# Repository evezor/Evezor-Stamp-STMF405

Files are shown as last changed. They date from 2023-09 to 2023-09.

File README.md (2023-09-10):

# Evezor-Stamp-STMF405
*please note this board is has been deprecated. 

The Evezor Stamp is a castellated carrier for the stmf405 chip with CAN networking and memory for Evezor's Edge network

The intent was that I could have this made by a higher quality shop with better pick and place machines than I had at the time. 
This was originally designed early in the pandemic and then the STM chips became completely unavailable. 
It worked pretty good, but in the end I'm glad I changed chipsets for a number of reasons. 
For one, I think I would have not liked using these so much. The boards I designed for this had this module on the back. Don't do double sided stuff unless absolutely necessary. Additionally, changing chips right in the early stages provided me with the knowledge of the location of the boundaries between chips. This was and is good knowledge. 

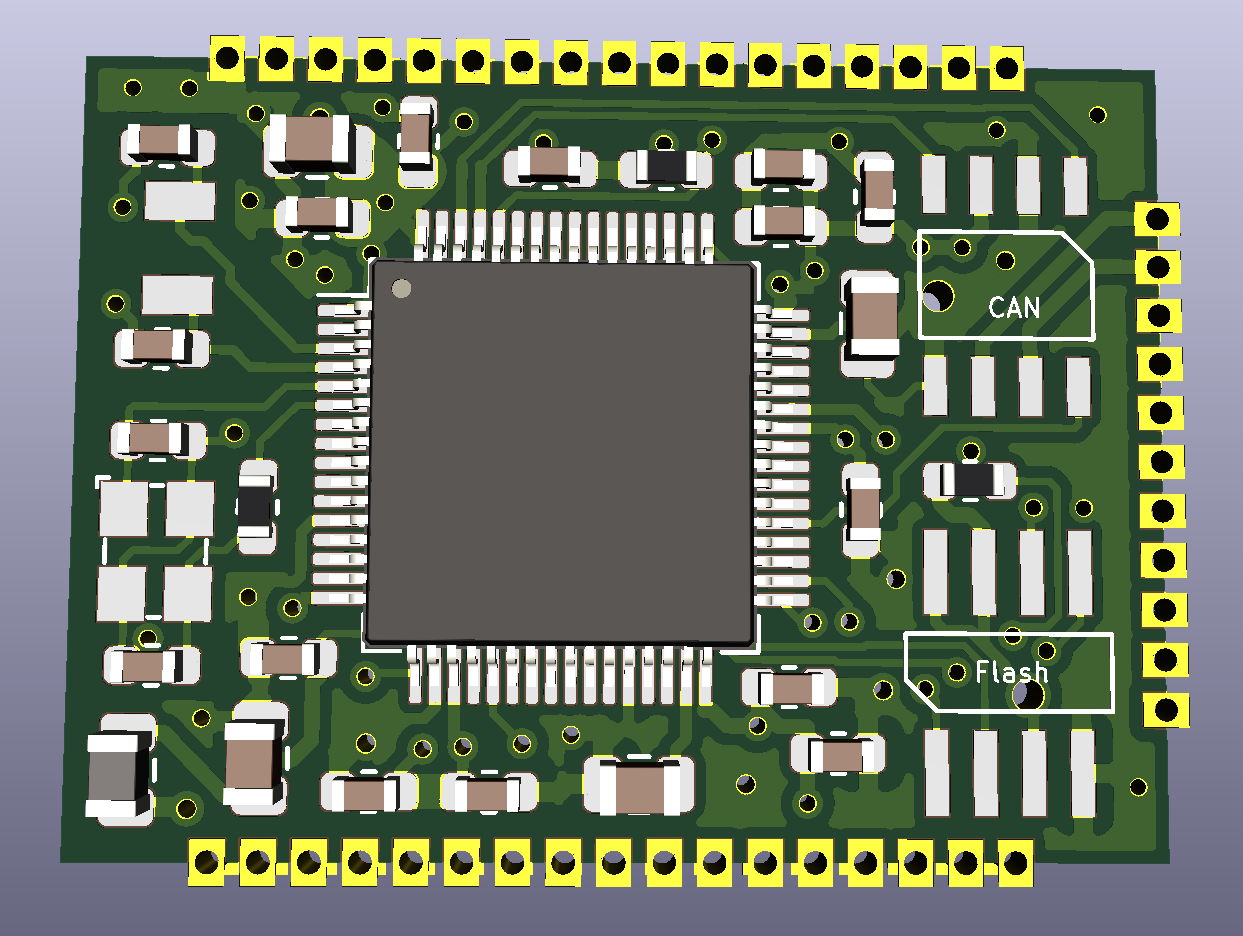
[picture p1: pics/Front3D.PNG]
front_view


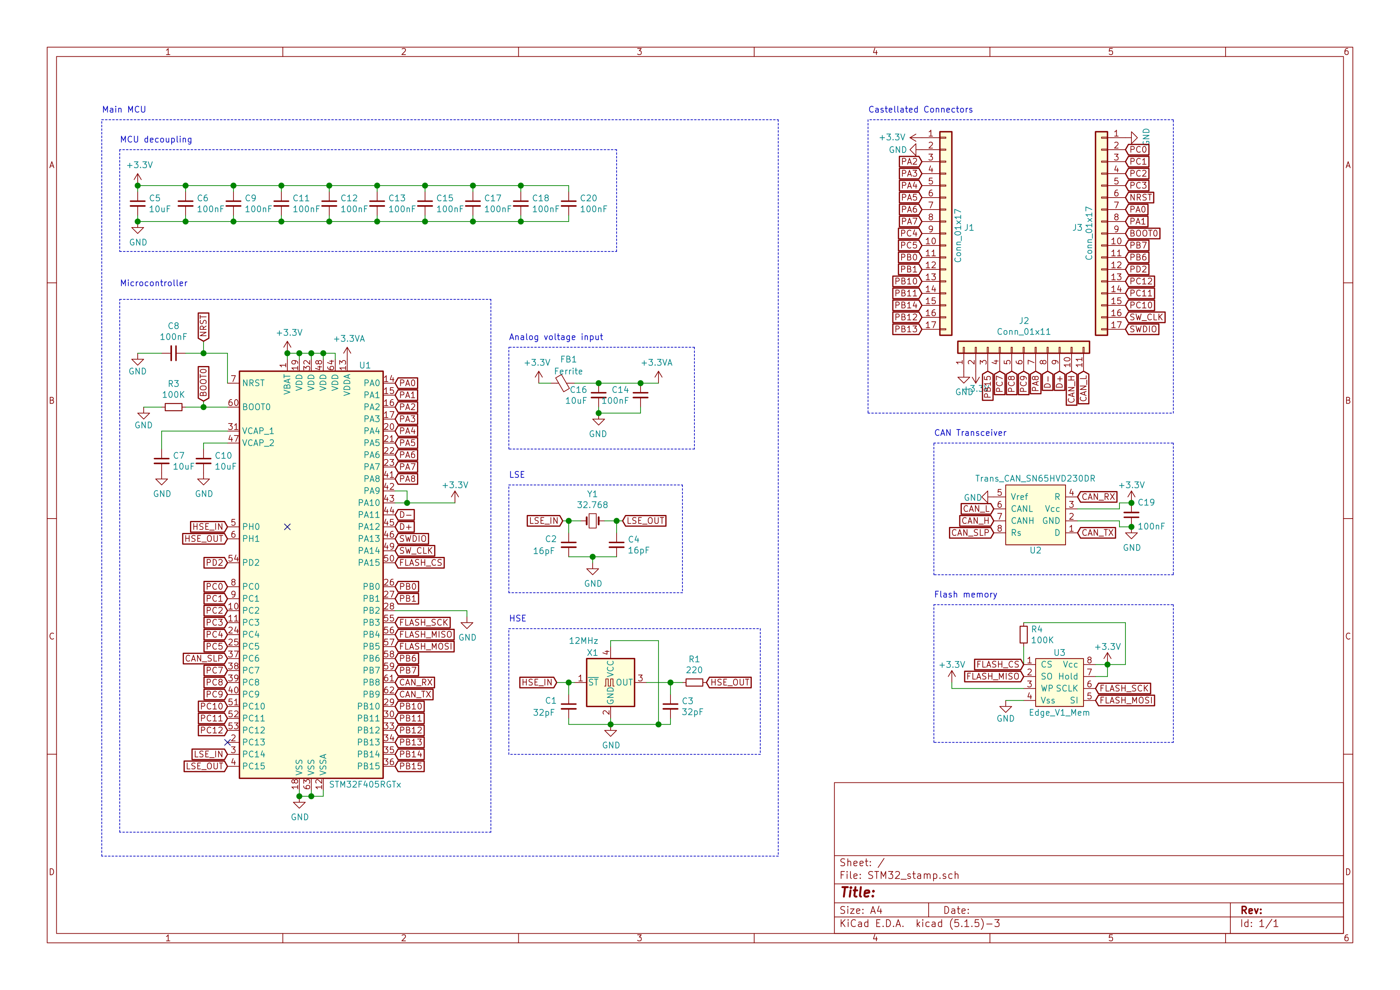
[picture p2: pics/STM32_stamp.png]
schematic


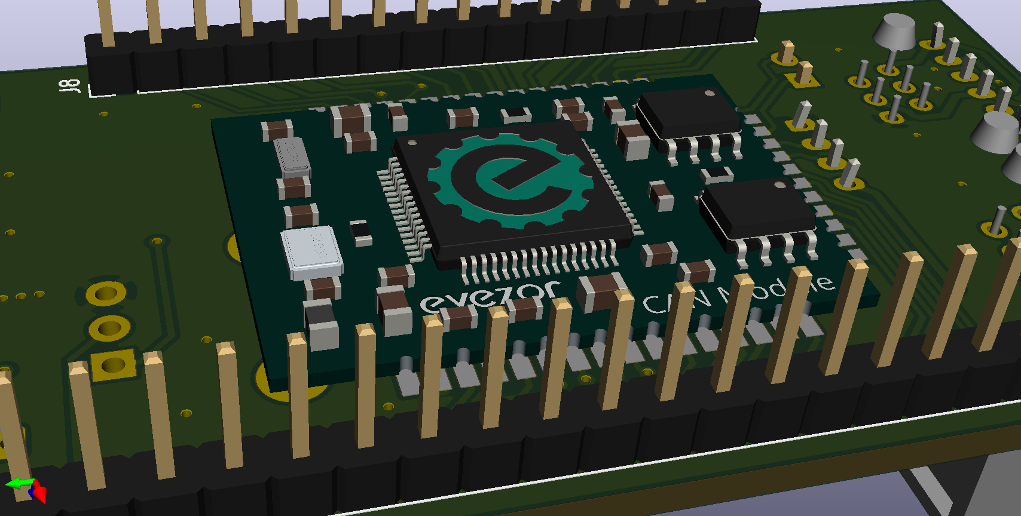
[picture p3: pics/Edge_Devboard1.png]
3d


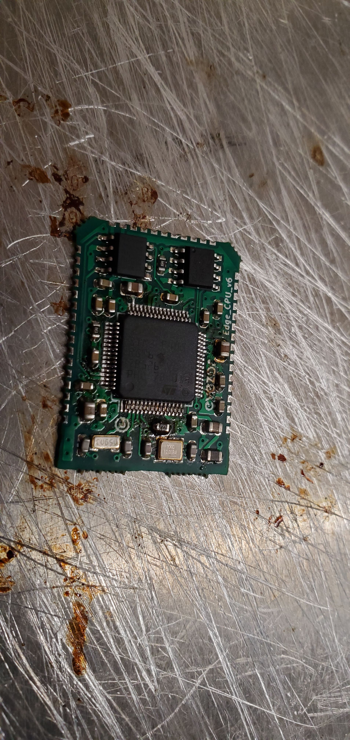
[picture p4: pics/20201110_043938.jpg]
stamp


I also developed a test and programming jig. It worked ok as well.
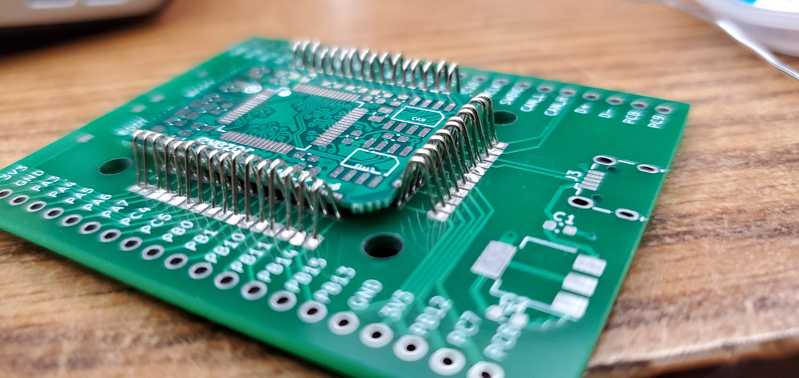
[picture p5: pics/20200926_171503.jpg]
test


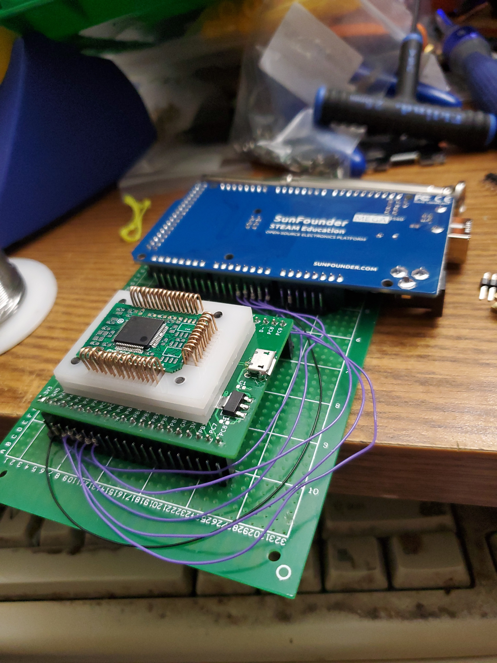
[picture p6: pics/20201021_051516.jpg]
mega


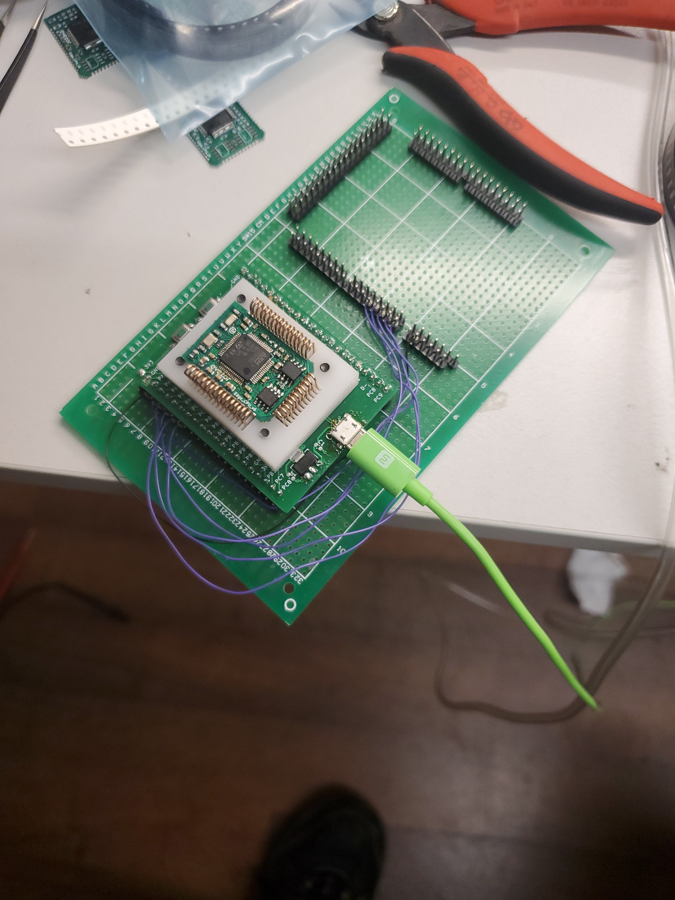
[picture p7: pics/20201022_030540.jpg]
empty


Evezor® and all associated marks, logos, and designs are registered trademarks and protected by copyright. Unauthorized use or reproduction of these trademarks and copyrighted materials is strictly prohibited

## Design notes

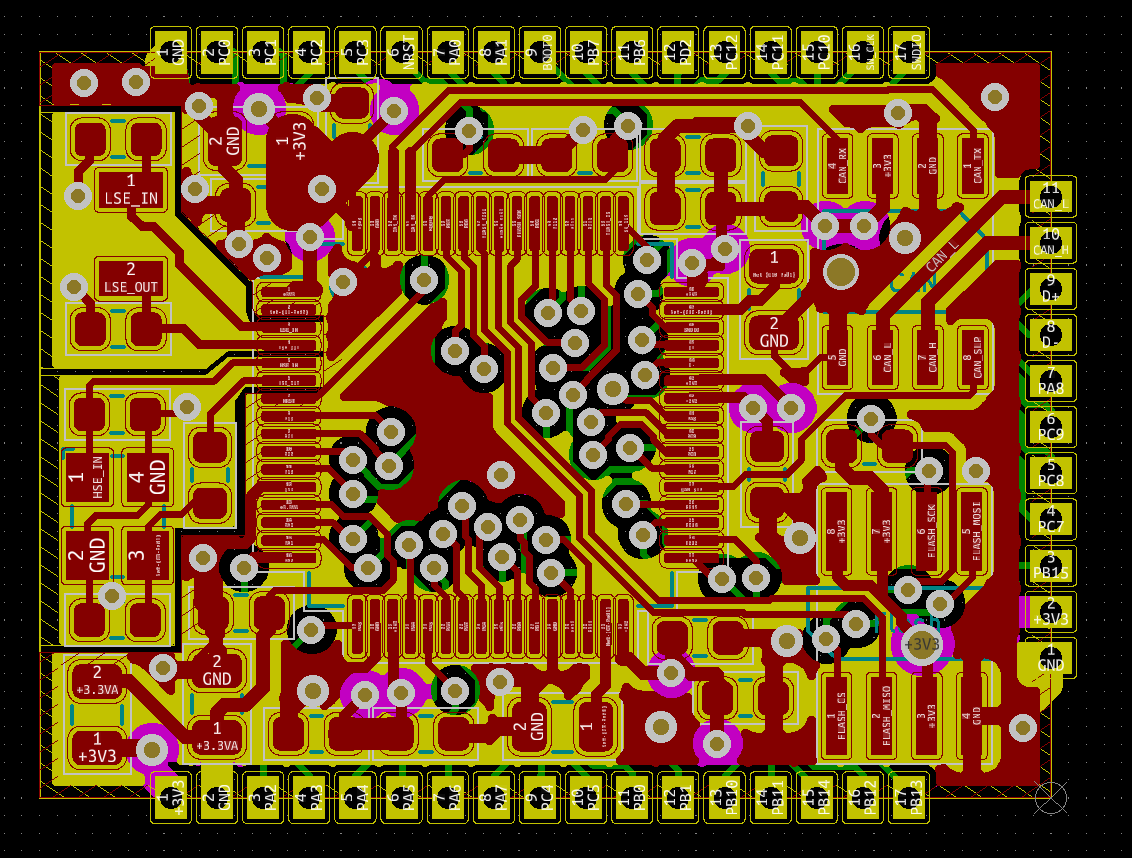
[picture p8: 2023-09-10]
pics/FrontCopper.PNG

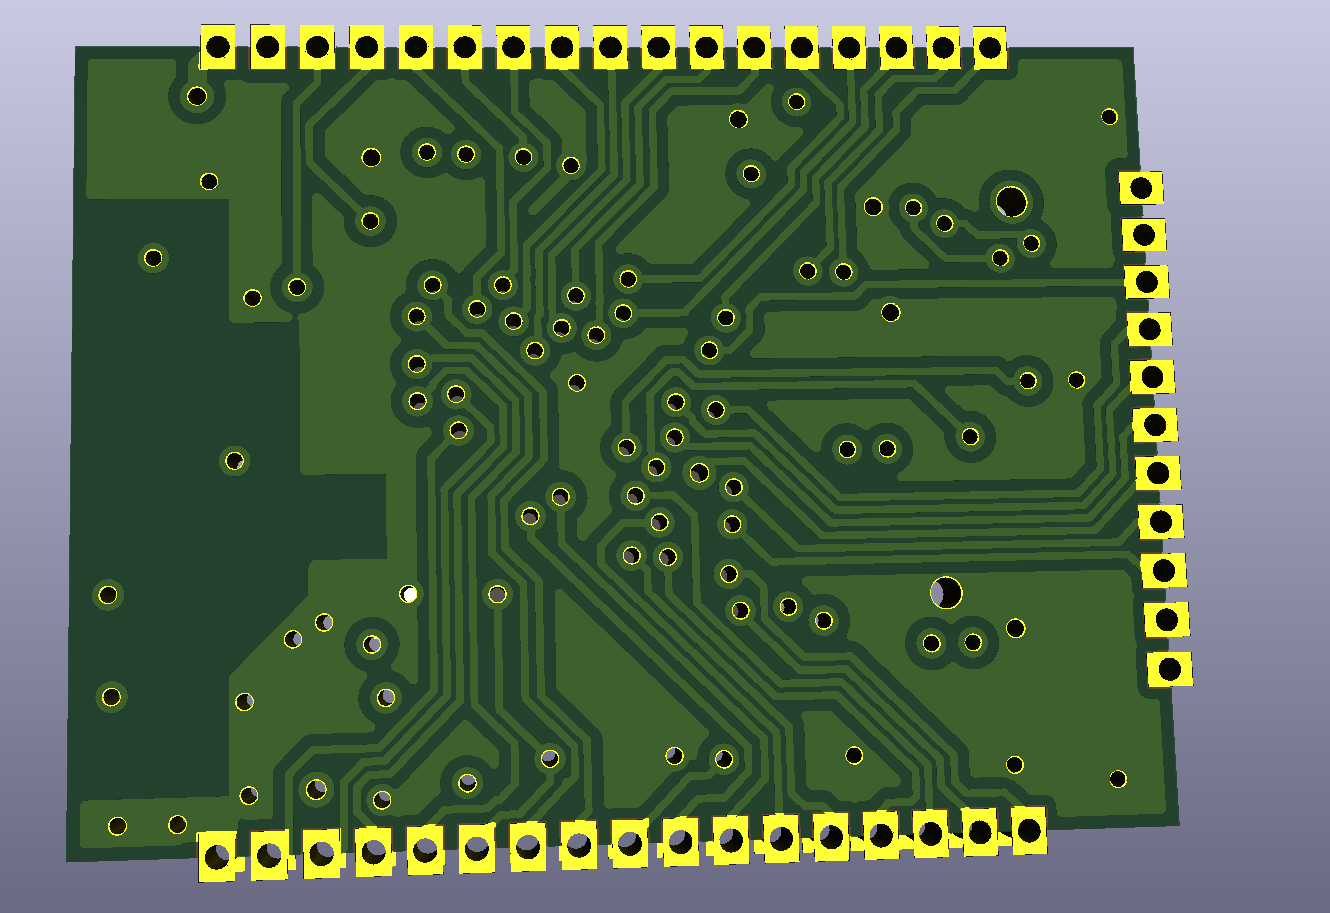
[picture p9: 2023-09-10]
pics/Back3D.PNG

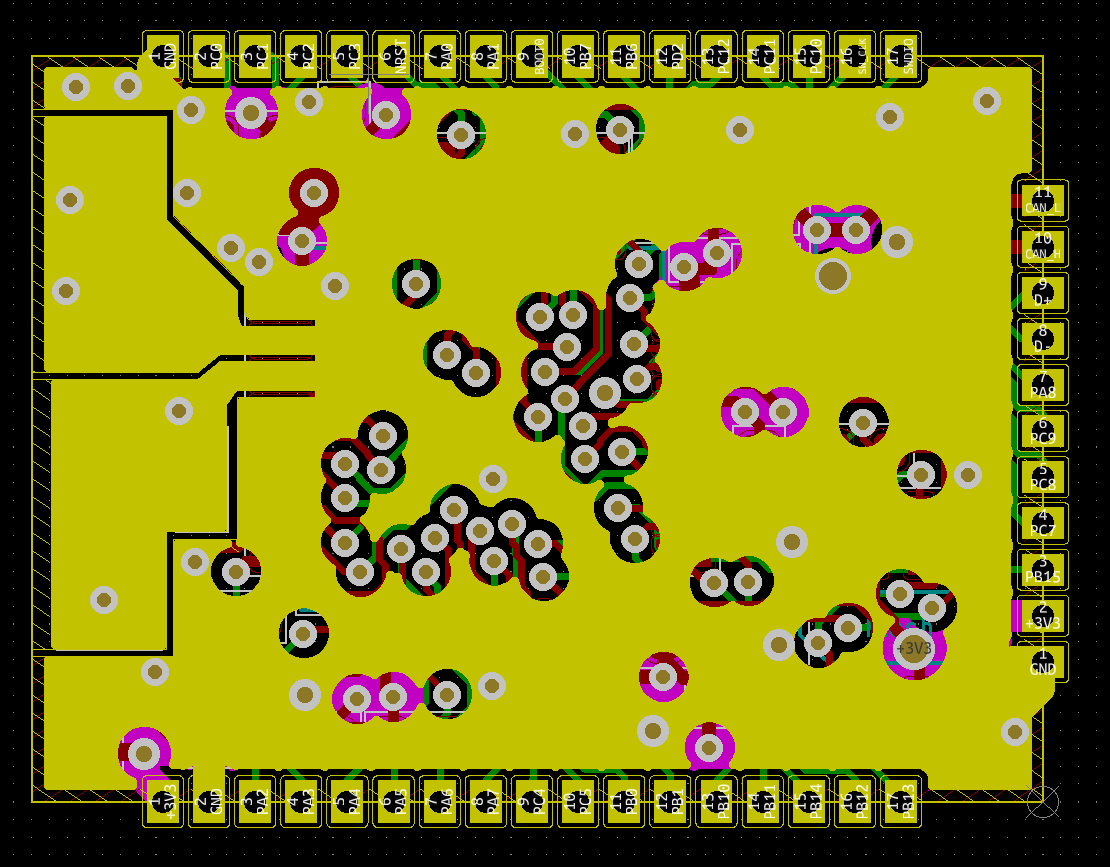
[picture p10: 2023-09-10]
pics/GroundPour.PNG

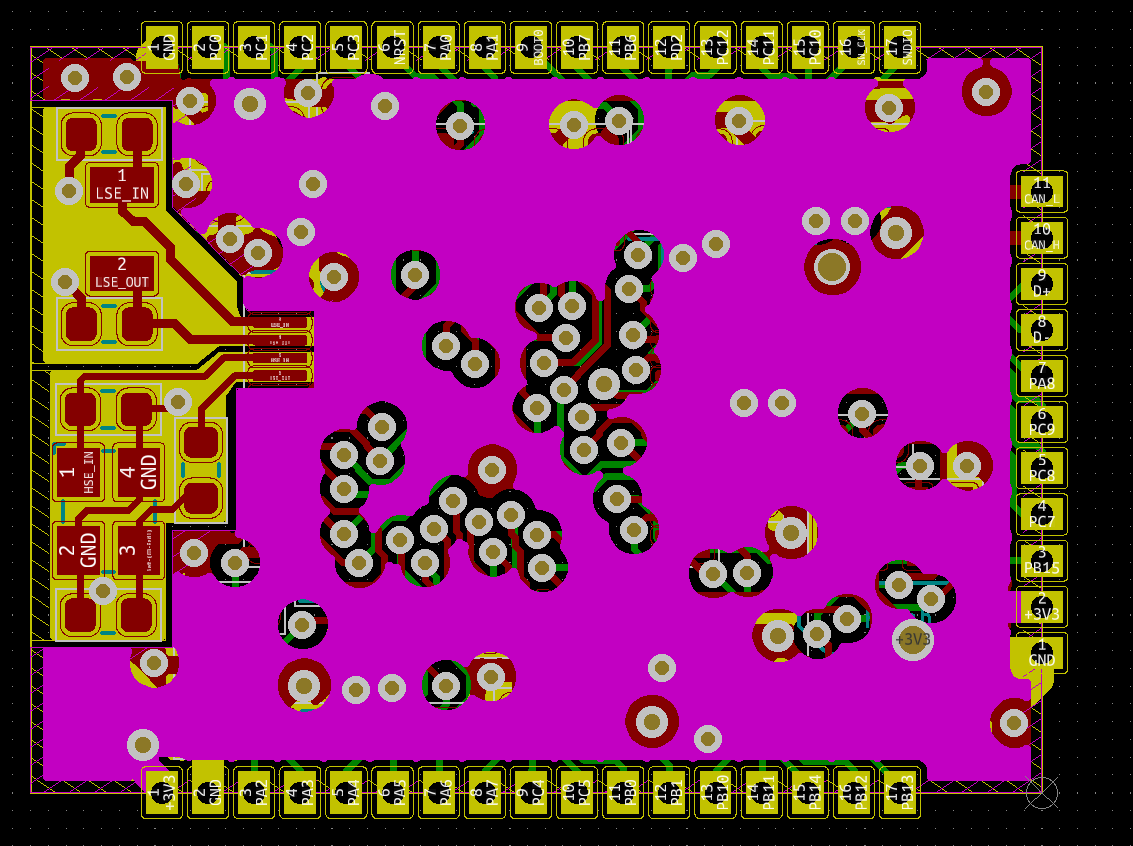
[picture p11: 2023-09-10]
pics/3V3.PNG

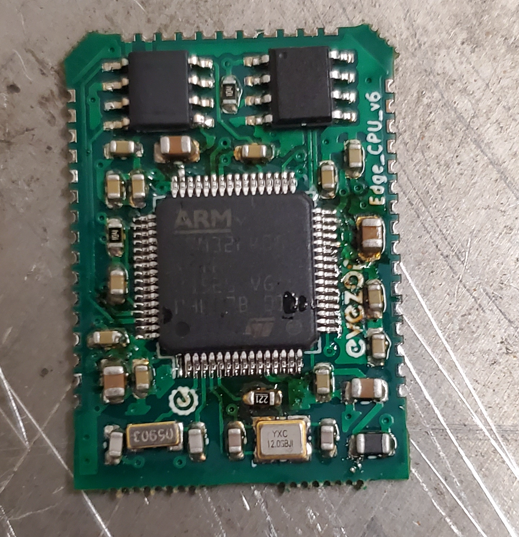
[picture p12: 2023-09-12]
pics/sm.PNG

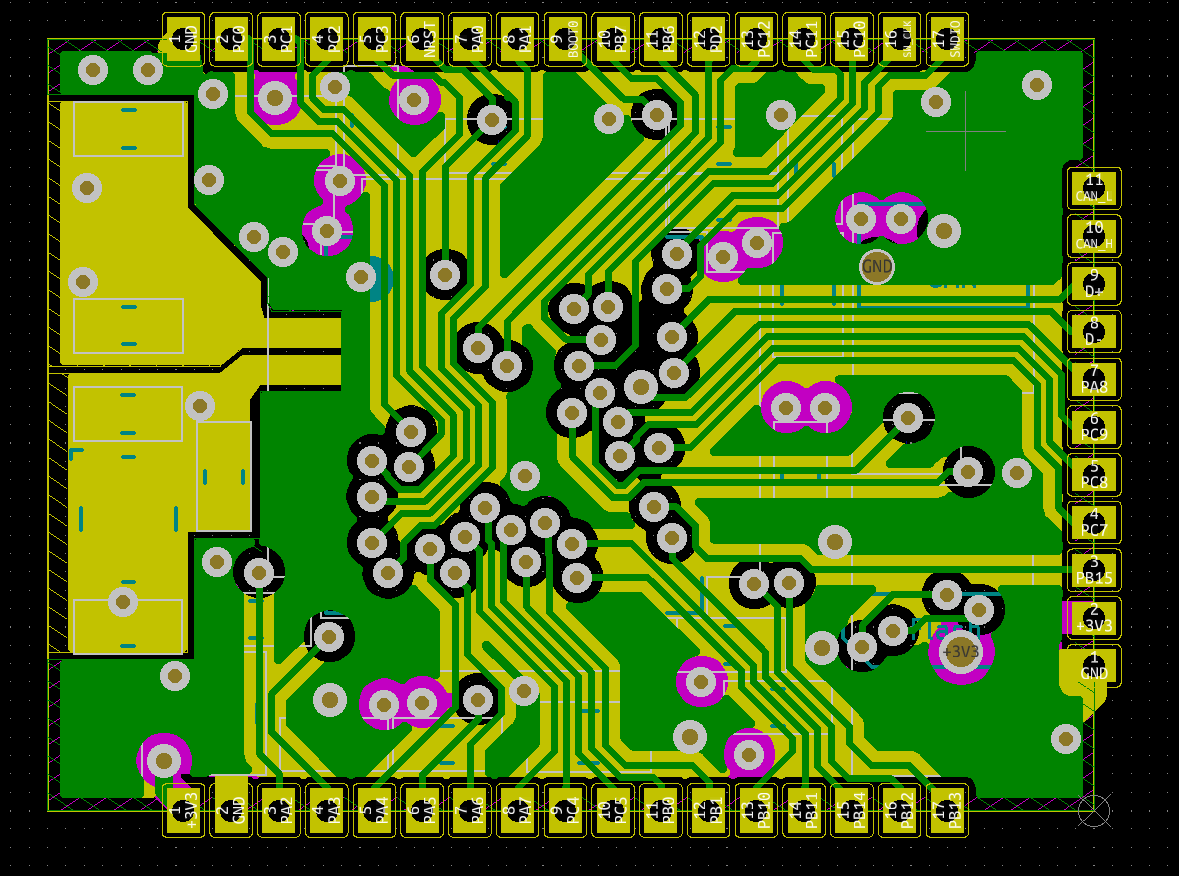
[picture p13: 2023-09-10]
pics/BackCopper.PNG

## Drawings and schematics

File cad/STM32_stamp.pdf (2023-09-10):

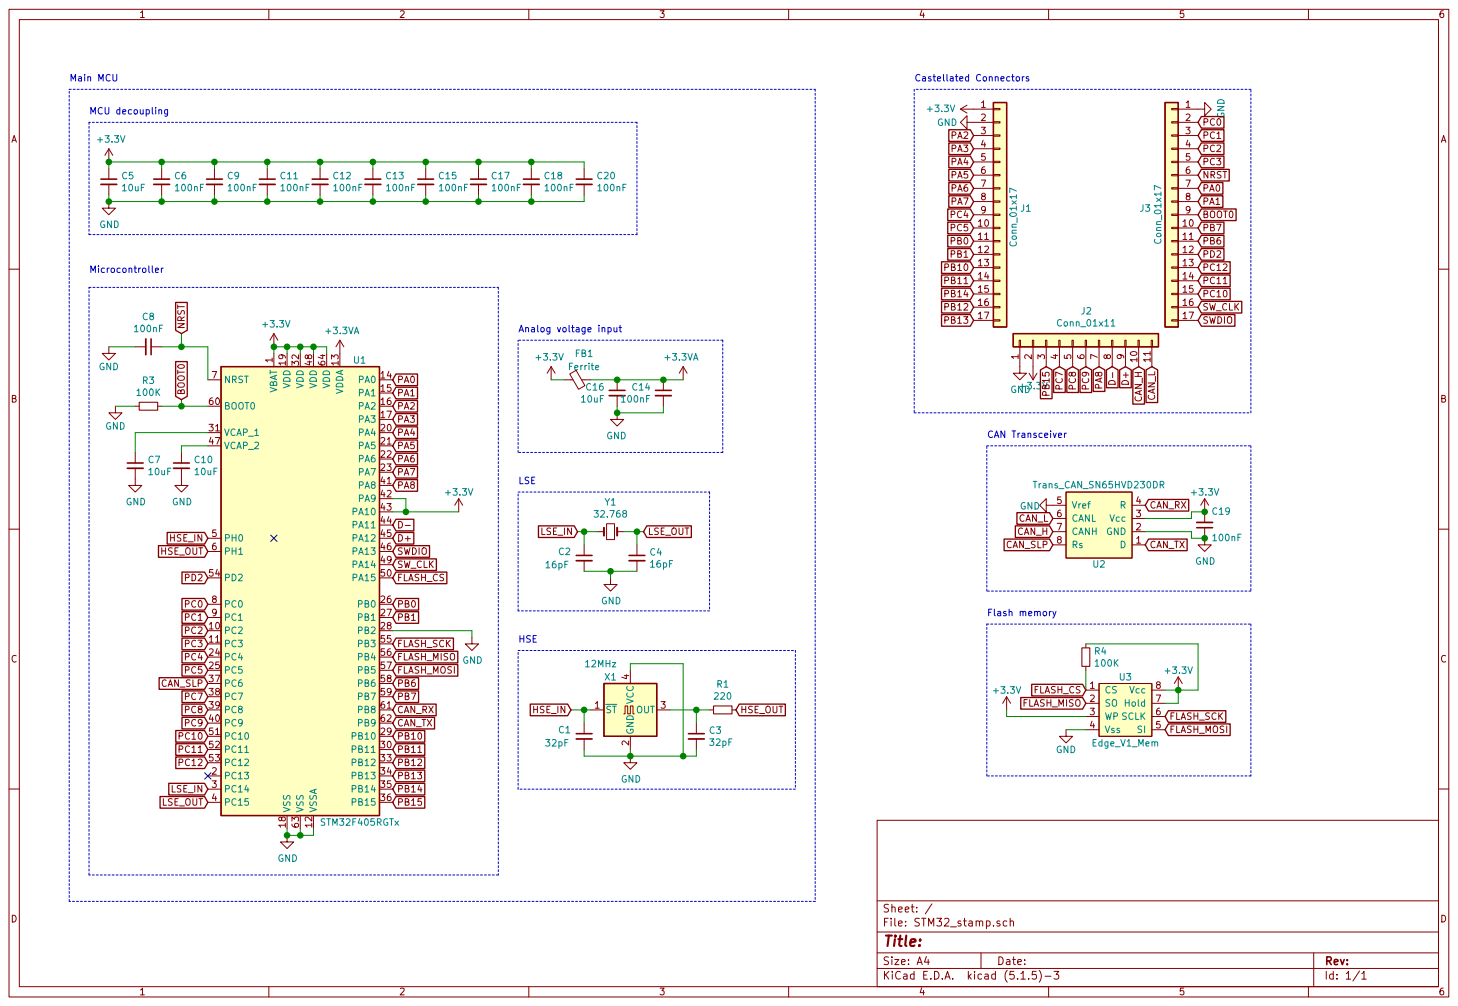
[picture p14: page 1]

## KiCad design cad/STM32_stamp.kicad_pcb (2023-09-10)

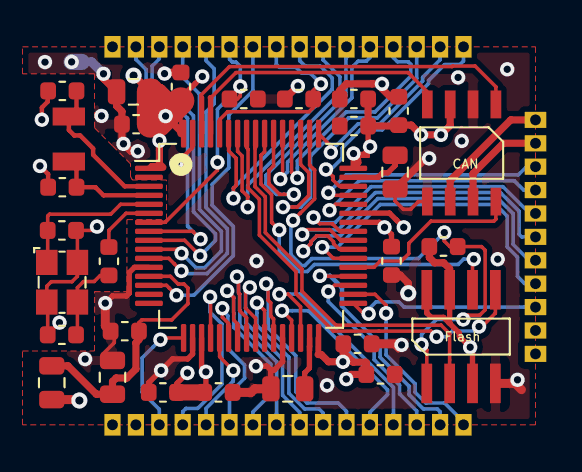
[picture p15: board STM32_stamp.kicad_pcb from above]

Board: 4 copper layers, 32 parts (0 on the bottom side), 55 nets.

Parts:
C1, C3: 20pF; C_0603_1608Metric
C2, C4: 12pF; C_0603_1608Metric
C5, C7, C10, C16: 10uF; C_0805_2012Metric
C6, C8, C9, C11, C12, C13, C14, C15, C17, C18, C19, C20: 100nF; C_0603_1608Metric
FB1: Ferrite; L_0805_2012Metric
J1, J3: Conn_01x16; CASTELLATED_16
J2: Conn_01x11; CASTELLATED_11
R1: 220; R_0603_1608Metric
R3, R4: 100K; R_0603_1608Metric
U1: STM32F405RGTx; LQFP-64_10x10mm_P0.5mm
U2: Trans_CAN_SN65HVD230DR; CAN-TRANS-SN65HVD230DR
U3: Edge_V1_Mem; STM32_SOIC8_MEM
Y1: 32.768; CRYSTAL_SEIKO_32.768_SC-32S32.768kHz20PPM12.5pF
Y2: 12MHz; Crystal_3.2X2.5X0.8_C9002

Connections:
+3.3VA: C14.1, C16.1, FB1.2, U1.13
+3V3: C5.1, C6.1, C9.1, C11.1, C12.1, C13.1, C15.1, C17.1, C18.1, C19.2, C20.1, FB1.1, J1.1, J2.2, R4.1, U1.1, U1.19, U1.32, U1.42, U1.43, U1.48, U1.64, U2.3, U3.3, U3.7, U3.8
BOOT0: J3.8, R3.1, U1.60
CAN_H: J2.10, U2.7
CAN_L: J2.11, U2.6
CAN_RX: U1.61, U2.4
CAN_SLP: U1.37, U2.8
CAN_TX: U1.62, U2.1
D+: J2.9, U1.45
D-: J2.8, U1.44
FLASH_CS: R4.2, U1.50, U3.1
FLASH_MISO: U1.56, U3.2
FLASH_MOSI: U1.57, U3.5
FLASH_SCK: U1.55, U3.6
GND: C1.2, C2.2, C3.2, C4.2, C5.2, C6.2, C7.2, C8.2, C9.2, C10.2, C11.2, C12.2, C13.2, C14.2, C15.2, C16.2, C17.2, C18.2, C19.1, C20.2, J1.2, J2.1, J3.1, R3.2, U1.12, U1.18, U1.28, U1.63, U2.2, U2.5, U3.4, Y2.2, Y2.4
HSE_IN: C1.1, U1.5, Y2.1
HSE_OUT: R1.1, U1.6
LSE_IN: C2.1, U1.3, Y1.1
LSE_OUT: C4.1, U1.4, Y1.2
NRST: C8.1, J3.6, U1.7
unnamed: C3.1, R1.2, Y2.3
unnamed: C7.1, U1.31
unnamed: C10.1, U1.47
PA0: J3.7, U1.14
PA3: J1.3, U1.17
PA4: J1.4, U1.20
PA5: J1.5, U1.21
PA6: J1.6, U1.22
PA7: J1.7, U1.23
PA8: J2.7, U1.41
PB0: J1.10, U1.26
PB1: J1.11, U1.27
PB6: J3.10, U1.58
PB7: J3.9, U1.59
PB10: J1.12, U1.29
PB11: J1.13, U1.30
PB12: J2.3, U1.33
PB13: J1.16, U1.34
PB14: J1.14, U1.35
PB15: J1.15, U1.36
PC0: J3.2, U1.8
PC1: J3.3, U1.9
PC2: J3.4, U1.10
PC3: J3.5, U1.11
PC4: J1.8, U1.24
PC5: J1.9, U1.25
PC7: J2.4, U1.38
PC8: J2.5, U1.39
PC9: J2.6, U1.40
PC10: J3.14, U1.51
PC11: J3.13, U1.52
PC12: J3.12, U1.53
PD2: J3.11, U1.54
SWDIO: J3.16, U1.46
SW_CLK: J3.15, U1.49
